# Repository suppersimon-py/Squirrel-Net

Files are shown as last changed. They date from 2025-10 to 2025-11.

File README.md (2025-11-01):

<div align="center">
  <a href="https://github.com/suppersimon-py">
    SupperSimon
  </a>

  <h2>Squirrel-Core</h2>
  <h2>NOT FINISHED</h2>
  <p>
    <strong>SquirrelCore</strong> is an open-source PCB built around the <strong>ESP32-S3</strong> and <strong>SX1262</strong>.
    It is designed for long-range mesh networking using the open-source 
    <a href="https://meshtastic.org" target="_blank" rel="noopener noreferrer">Meshtastic</a> firmware.
    It can function as a client, node, or repeater in a distributed network.
  </p>
</div>
<a href="https://github.com/suppersimon-py">
    
</a>
  <p>
    I wanted to design this as a challenge and a learning expirence on radio circuity for some time now, but without the funding (I'm kinda broke rn) this idea of mine wouldn't come to reality.
  </p>
  <h3>Continuing the development process</h3>
  <p>
    My plans are to not just stop on the PCB design but to also design a case around it. I am a visual modeler, I can't start work on the case until i have it in hand and can mesure and test fit,
    But I can assure I do have intresting design ideas for it. 
  </p>
  <p>
    Currently I have a github workflow that will automatically update, build, and release new versions of the meshtaic firmware to the realses page.
  </p>
  <p>
    I also need to fix somethings and test the actual firmware firmware.
  </p>

<div align="left">
  <h3>Features</h3>
  <ul>
    <li>ESP32-S3 microcontroller</li>
    <li>8MB Flash memory</li>
    <li>LoRaWAN, Wi-Fi, Bluetooth, and USB-C serial connectivity</li>
    <li>Adjustable battery charging: 400 mA or 1 A</li>
    <li>OLED display</li>
    <li>BME280 sensor (temperature, humidity, pressure)</li>
    <li>GPS module</li>
  </ul>
</div>

<div align="center">
  <h3>Meshtastic Links</h3>
  <p>
    <a href="https://meshtastic.org" style="text-decoration:none; font-weight:bold;">Get Started</a><br/>
    - <a href="https://meshtastic.org/docs/development/firmware/build">Building Instructions</a> – Learn how to compile the firmware from source.<br/>
    - <a href="https://meshtastic.org/docs/getting-started/flashing-firmware/esp32/">Flashing Instructions</a> – Install or update the firmware on your device.
  </p>
</div>

<div align="center">
  <h3>Licensing</h3>
</div>

<div align="left">
  <ul>
    <li>The core Meshtastic firmware in <code>/firmware/meshtastic</code> remains under its original license (as provided by the Meshtastic project).</li>
    <li>The SquirrelCore variant files in <code>/firmware/meshtastic/variants</code> are MIT-licensed (Copyright 2025 Supper Simon).</li>
    <li>When updating the repository, the variant is copied into Meshtastic, but the original Meshtastic license still applies to its code.</li>
  </ul>
</div>

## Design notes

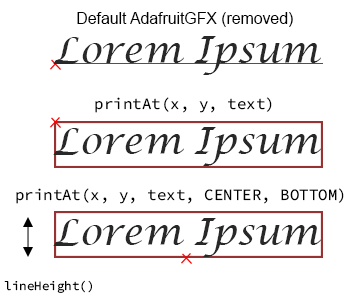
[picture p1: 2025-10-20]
firmware/meshtastic/src/graphics/niche/InkHUD/docs/appletfont.png

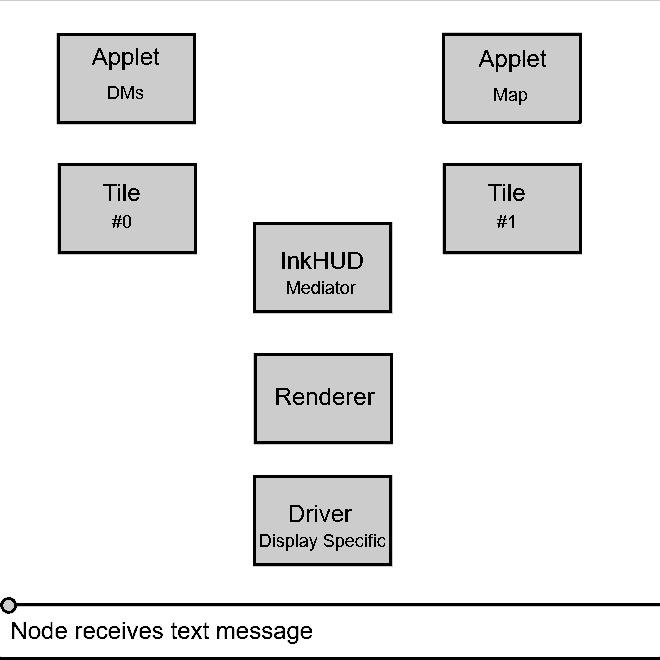
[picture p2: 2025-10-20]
firmware/meshtastic/src/graphics/niche/InkHUD/docs/rendering.gif

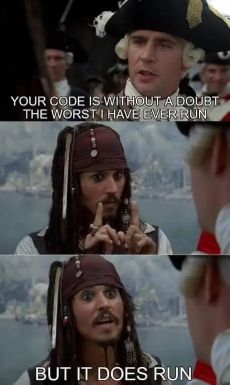
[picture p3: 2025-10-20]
firmware/meshtastic/src/graphics/niche/InkHUD/docs/disclaimer.jpg

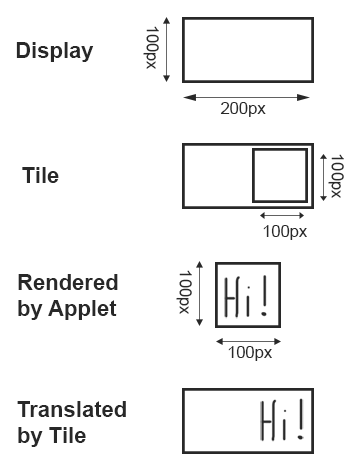
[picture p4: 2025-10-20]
firmware/meshtastic/src/graphics/niche/InkHUD/docs/tile_translation.png

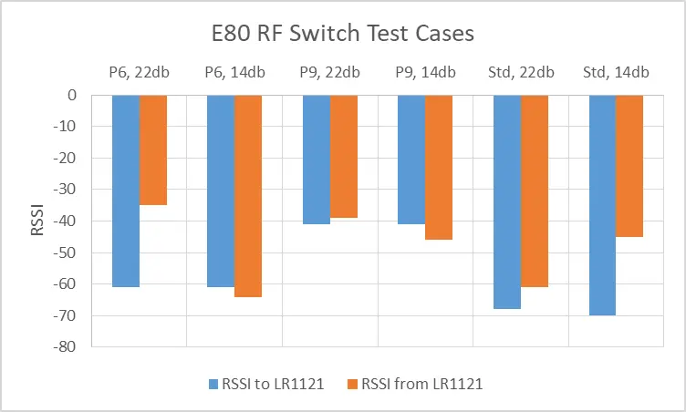
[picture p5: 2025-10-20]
firmware/meshtastic/variants/diy/nrf52_promicro_diy_tcxo/E80_RSSI_per_case.webp

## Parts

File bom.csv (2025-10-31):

id | designator | designation | qty per board | LCSC # | Footprint | PCBA Part | Price per Unit | Total Price | Purchased from
1 | Flash1 | Switch | 1 | 4809-SKRKAGE020CT-ND | SW_SPST_TS-1088-xR020 | no | 0.41 | 0.82 | digikey
2 | J5 | I2C OLED | 1 | 4863-WEA012832FWPP3N00000-ND | PinHeader_1x04_P2.54mm_Vertical | no | 5.02 | 10.04 | digikey
3 | BZ1 | Buzzer | 1 | 102-3761-1-ND | Buzzer_CUI_CPT-9019S-SMT | no | 1.82 | 3.64 | digikey
4 | J1 | Battery | 1 | 1471-MIKROE-4473-ND |  | no | 13.08 | 26.16 | digikey
5 | C1,C11,C12,C13,C16,C17,C19,C25,C28,C36,C38,C39 | 100nF | 12 | C307331,C1525,C49062 | 0402_1005 | yes | 0.0045 | 0.108 | JLC_PCBA
6 | C2,C8,C30 | 10uF | 3 | C15525 | 0402_1005 | yes | 0.0051 | 0.0306 | JLC_PCBA
7 | C3,C14,C49,C60 | 12pF | 4 | C1547 | 0402_1005 | yes | 0.0011 | 0.0088 | JLC_PCBA
8 | C4,C6,C24,C43,C44 | 1uF | 5 | C52923 | 0402_1005 | yes | 0.0029 | 0.029 | JLC_PCBA
9 | C5,C7,C10,C18,C20,C22,C23,C27 | 0.1uF | 8 | C1525 | 0402_1005 | yes | 0.0012 | 0.0192 | JLC_PCBA
10 | C9,C29,C42,C45 | 10 µF | 4 | C15525 | 0402_1005 | yes | 0.0051 | 0.0408 | JLC_PCBA
11 | C15,C50 | 47pF | 2 | C1567 | 0402_1005 | yes | 0.001 | 0.004 | JLC_PCBA
12 | C26 | 2.2u | 1 | C12530 | 0402_1005 | yes | 0.0024 | 0.0048 | JLC_PCBA
13 | C31 | 15pF | 1 | C1548 | 0402_1005 | yes | 0.001 | 0.002 | JLC_PCBA
14 | C32 | 1nF | 1 | C1523 | 0402_1005 | yes | 0.0011 | 0.0022 | JLC_PCBA
15 | C33 | 39pF | 1 | C1563 | 0402_1005 | yes | 0.0011 | 0.0022 | JLC_PCBA
16 | C34,C35 | 3.3pF | 2 | C1565 | 0402_1005 | yes | 0.001 | 0.004 | JLC_PCBA
17 | C37 | 470nF | 1 | C1623 | 0402_1005 | yes | 0.007 | 0.014 | JLC_PCBA
18 | C40 | 10nF | 1 | C15195 | 0402_1005 | yes | 0.007 | 0.014 | JLC_PCBA
19 | C41 | 0.1 µF | 1 | C1525 | 0402_1005 | yes | 0.0012 | 0.0024 | JLC_PCBA
20 | D1 | IR26-21C_L110_TR8 | 1 | C73929 | LED_SMD:LED_1206_3216Metric | yes | 0.0459 | 0.0918 | JLC_PCBA
21 | D3 | SS14 | 1 | C2480 | Diode_SMD:D_SMA | yes | 0.0149 | 0.0298 | JLC_PCBA
22 | D7 | LED_A_RGB | 1 | C6785001 | LED_SMD:LED_RGB_Wuerth_150080M153000 | yes | 0.7815 | 1.563 | JLC_PCBA
23 | J1 | XH-2AW | 1 | C157932 | JST_GH_SM02B-GHS-TB_1x02-1MP_P1.25mm_Horizontal | yes | 0.1328 | 0.2656 | JLC_PCBA
24 | J2 | USB_C_Receptacle_USB2.0_14P | 1 | C2894897 | USB_C_Receptacle_HCTL_HC-TYPE-C-16P | yes | 0.0888 | 0.1776 | JLC_PCBA
25 | J3 | Conn_Coaxial | 1 | C411563 | PCM_JLCPCB:IPEX-SMD_BWIPX-1-001E | yes | 0.0644 | 0.1288 | JLC_PCBA
26 | L3 | 2nH | 1 | C77103 | 0402_1005 | yes | 0.0057 | 0.0114 | JLC_PCBA
27 | L5 | 9.1nH | 1 | C74297 | 0402_1005 | yes | 0.0035 | 0.007 | JLC_PCBA
28 | L6 | 4.7nH | 1 | C13595 | 0402_1005 | yes | 0.0026 | 0.0052 | JLC_PCBA
29 | L8 | 15uH | 1 | C3221788 | 0402_1005 | yes | 1.1715 | 2.343 | JLC_PCBA
30 | Q1 | FS8205A | 1 | C908265 | SOP65P640X120-8N | yes | 0.0653 | 0.1306 | JLC_PCBA
31 | R1,R2 | 5K1 | 2 | C14677 | 0402_1005 | yes | 0.0011 | 0.0044 | JLC_PCBA
32 | R3 | 0R | 1 | C17168 | 0402_1005 | yes | 0.0005 | 0.001 | JLC_PCBA
33 | R4 | 1Ω | 1 | C25147 | 0402_1005 | yes | 0.0004 | 0.0008 | JLC_PCBA
34 | R5 | 1k | 1 | C11702 | 0402_1005 | yes | 0.0006 | 0.0012 | JLC_PCBA
35 | R6,R8,R17 | 3k | 3 | C25559 | 0402_1005 | yes | 0.0005 | 0.003 | JLC_PCBA
36 | R7 | 220k | 1 | C25546 | 0402_1005 | yes | 0.0004 | 0.0008 | JLC_PCBA
37 | R11,R14 | 4.7k | 2 | C25744 | 0402_1005 | yes | 0.0006 | 0.0024 | JLC_PCBA
38 | R12 | 1K | 1 | C861188 | 0402_1005 | yes | 0.0231 | 0.0462 | JLC_PCBA
39 | R13 | 100k | 1 | C25741 | 0402_1005 | yes | 0.0006 | 0.0012 | JLC_PCBA
40 | R15 | 1.2k | 1 | C25862 | 0402_1005 | yes | 0.0006 | 0.0012 | JLC_PCBA
41 | R21,R22 | 10K | 2 | C25744 | 0402_1005 | yes | 0.001 | 0.004 | JLC_PCBA
42 | U1 | BME280 | 1 | C92489 | Bosch_LGA-8_2.5x2.5mm_P0.65mm_ClockwisePinNumbering | yes | 2.9655 | 5.931 | JLC_PCBA
43 | U2 | PE4259 | 1 | C47117600 | bulk:SOT65P215X110-6N | yes | 0.1361 | 0.2722 | JLC_PCBA
44 | U3 | SX1262 | 1 | C191341 | Package_DFN_QFN:QFN-24-1EP_4x4mm_P0.5mm_EP2.6x2.6mm | yes | 3.102 | 6.204 | JLC_PCBA
45 | U4 | DW01A | 1 | C351410 | Package_TO_SOT_SMD:SOT-23-6 | yes | 0.0324 | 0.0648 | JLC_PCBA
46 | U6 | USBLC6-2SC6 | 1 | C7519 | Package_TO_SOT_SMD:SOT-23-6 | yes | 0.1013 | 0.2026 | JLC_PCBA
47 | U7 | ESP32-S3FN8 | 1 | C2913196 | QFN40P700X700X90-57N | yes | 3.942 | 7.884 | JLC_PCBA
48 | U8 | TP4056-42-ESOP8 | 1 | C16581 | SOIC-8-1EP_3.9x4.9mm_P1.27mm_EP2.41x3.3mm_ThermalVias | yes | 0.1719 | 0.3438 | JLC_PCBA
49 | U10 | AP2112K-3.3 | 1 | C23380830 | Package_TO_SOT_SMD:SOT-23-5 | yes | 0.0968 | 0.1936 | JLC_PCBA
50 | X1 | GPS_PA1010D | 1 | C9900050424 | Adafruit PA1010D Mini GPS:GPS_PA1010D | yes | 0.0365 | 0.073 | JLC_PCBA
51 | Y1 | 32.768 kHz | 1 | C32346 | Crystal:Crystal_SMD_3215-2Pin_3.2x1.5mm | yes | 0.1757 | 0.3514 | JLC_PCBA
52 | Y2 | Crystal_GND24 | 1 | C9900039190 | Crystal:Crystal_SMD_3225-4Pin_3.2x2.5mm | yes | 0.0365 | 0.073 | JLC_PCBA
53 | Y3 | 40MHz(10ppm) | 1 | C5261125 | Crystal:Crystal_SMD_2520-4Pin_2.5x2.0mm | yes | 0.0882 | 0.1764 | JLC_PCBA

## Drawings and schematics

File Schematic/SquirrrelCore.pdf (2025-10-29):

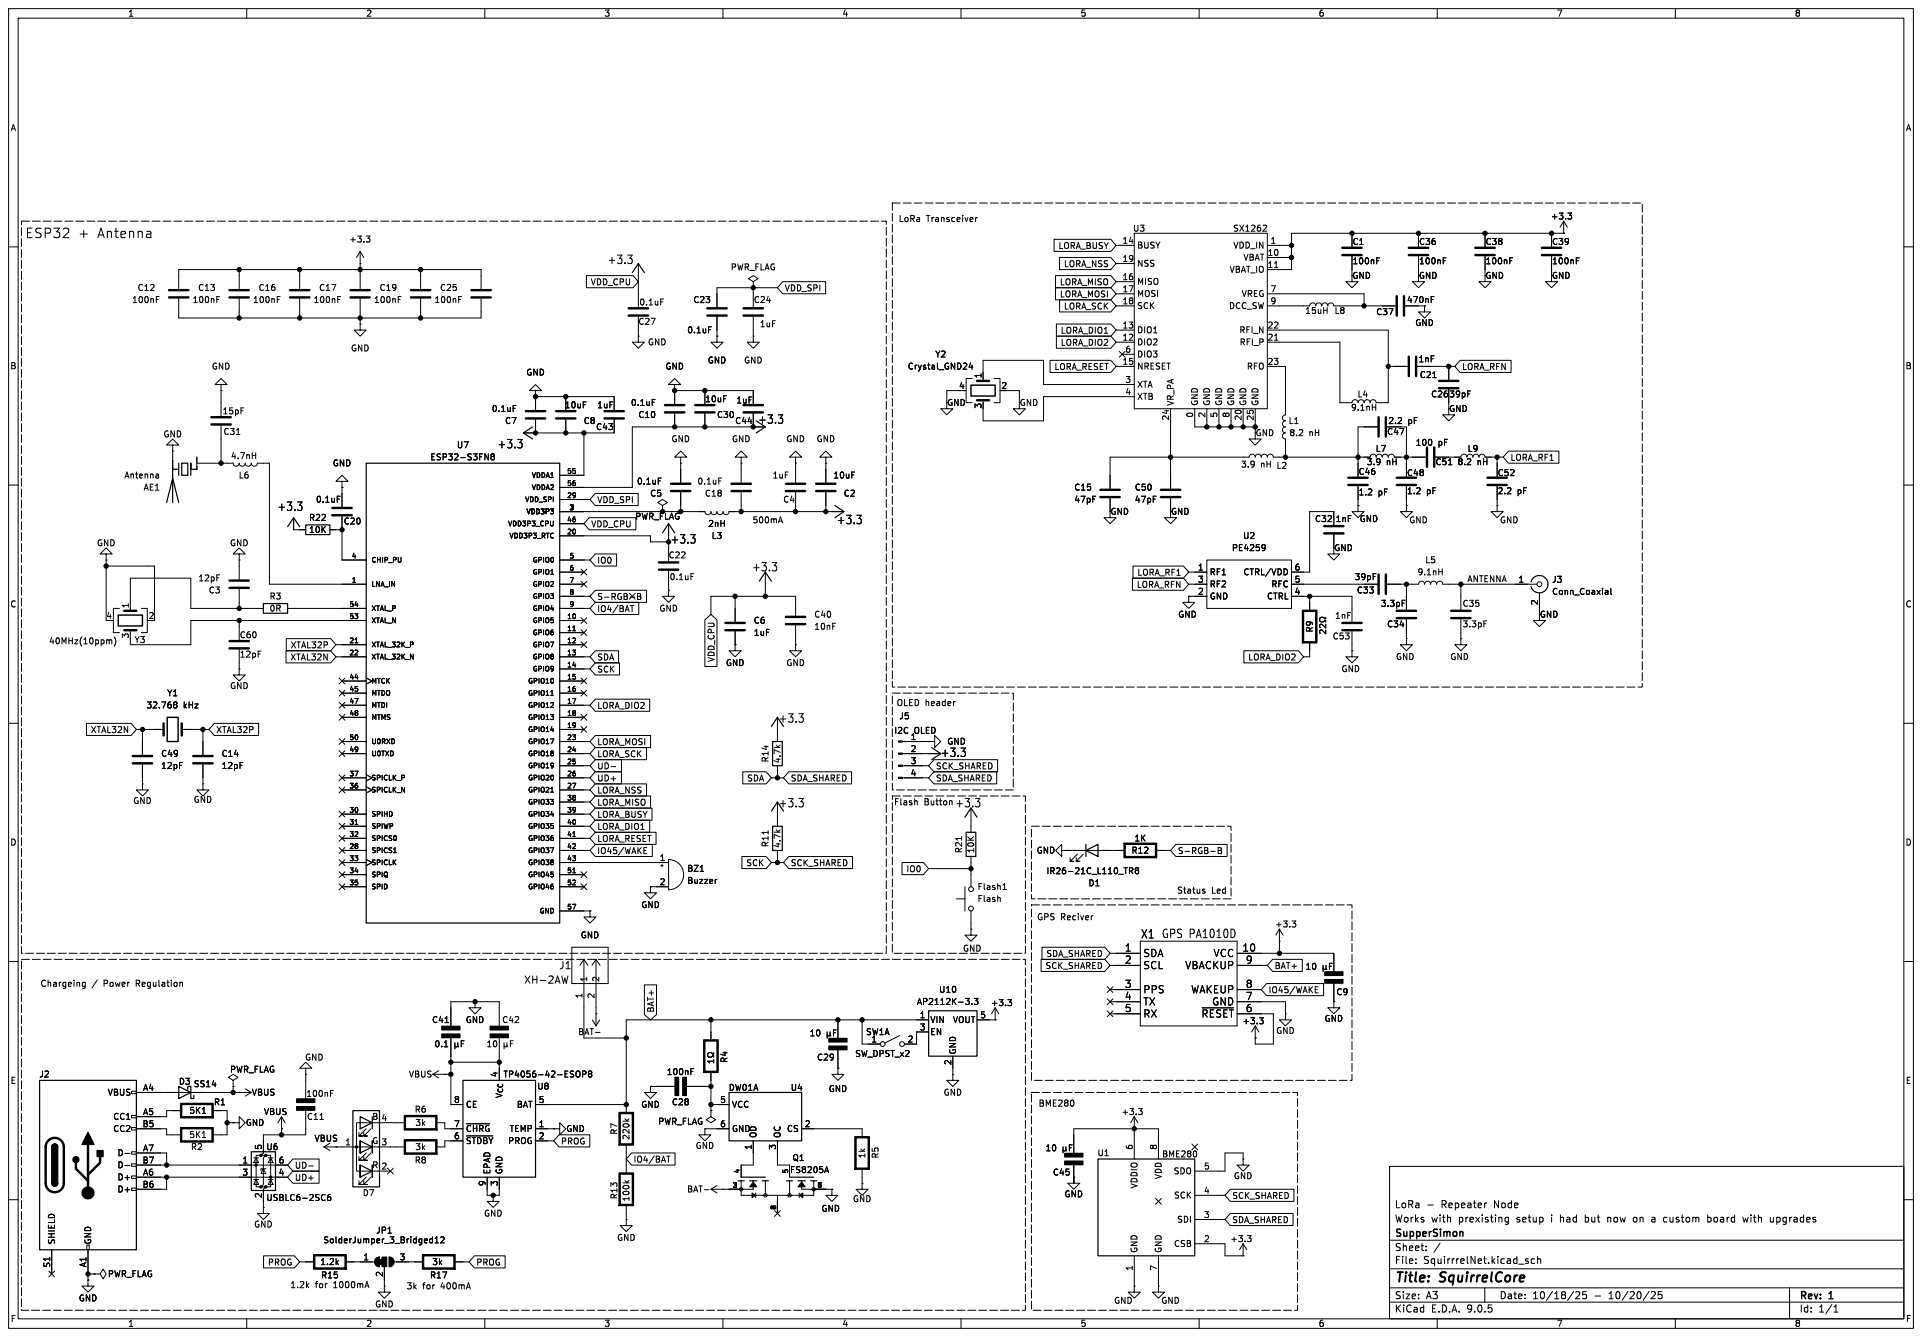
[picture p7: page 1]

8 GND 20 GND 25 VDD_IN 1 VBAT 10 VBAT_IO 11 VREG 7 DCC_SW 9 RFI_N 22 RFI_P 21 RFO 23 U3 SX1262 GND

1.2k for 1000mA Chargeing / Power Regulation

3 BAT 5 TEMP 1 PROG 2 GND

7 SDO 5 SCK 4 SDI 3 CSB 2 U1 BME280 GND

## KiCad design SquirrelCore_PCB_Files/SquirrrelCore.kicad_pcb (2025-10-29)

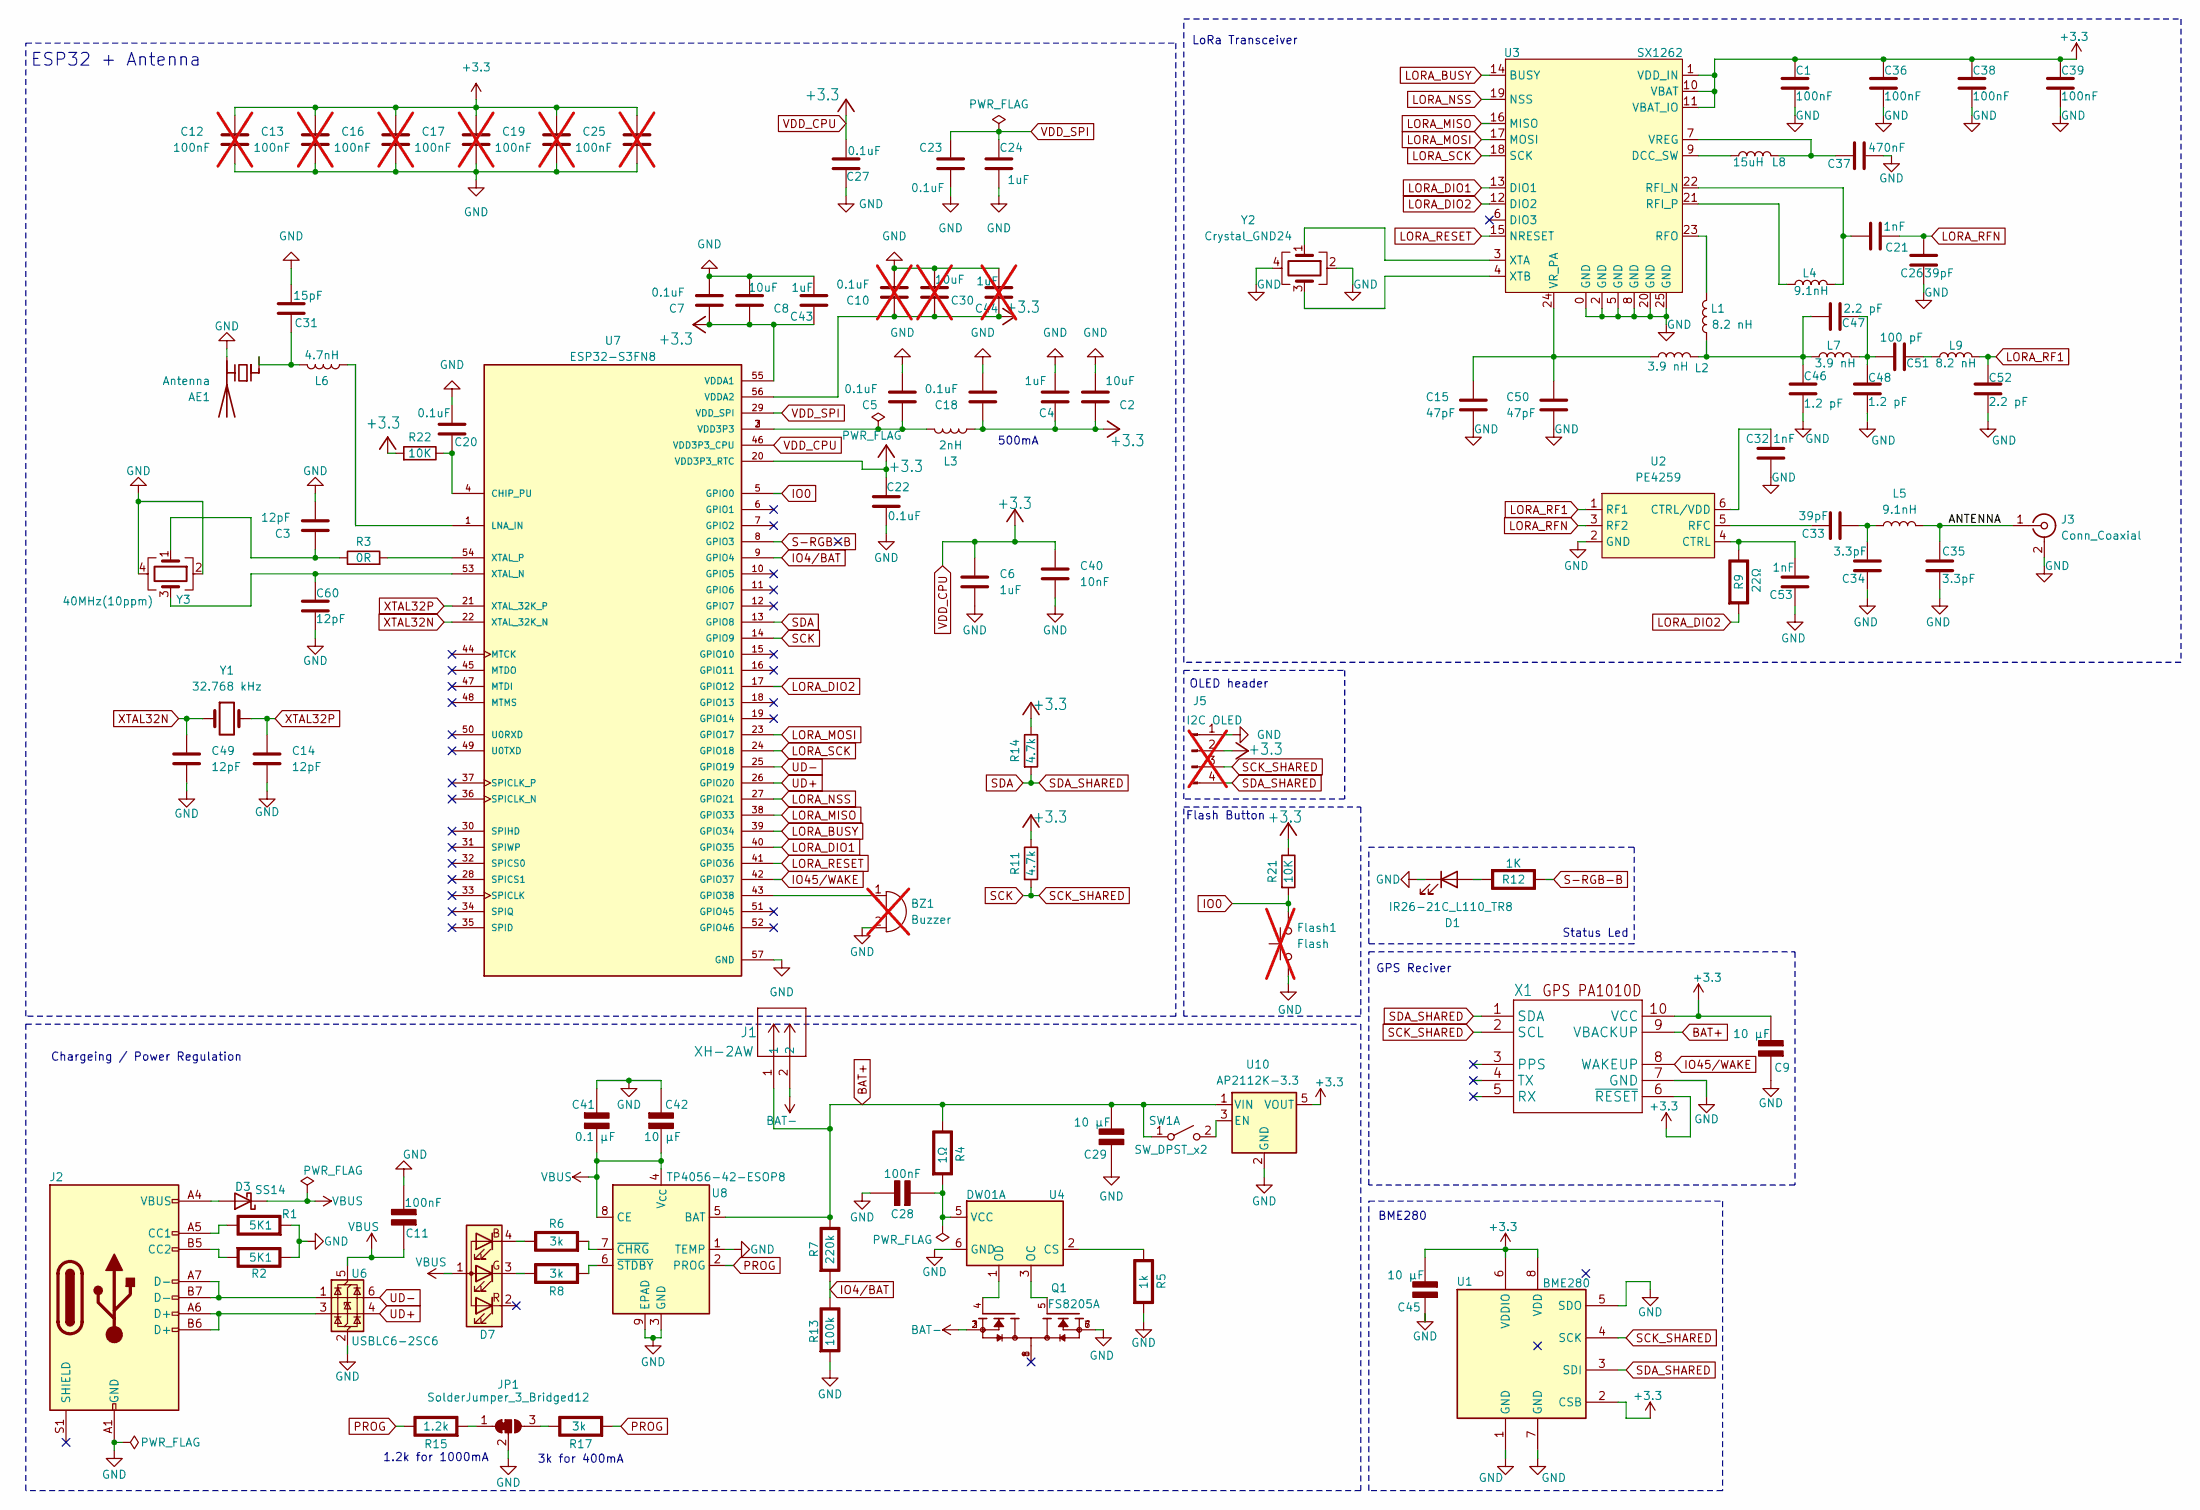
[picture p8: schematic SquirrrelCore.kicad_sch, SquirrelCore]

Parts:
AE1: Antenna; Texas_SWRA117D_2.4GHz_Left
BZ1: Buzzer; Buzzer_CUI_CPT-9019S-SMT; LCSC C95163; not fitted
C1, C36, C38, C39: 100nF; C_0402_1005Metric; LCSC C1525
C2, C8: 10uF; C_0402_1005Metric; MNF PART NUMBER C15525; LCSC C15525
C3, C14, C49, C60: 12pF; C_0402_1005Metric; MNF PART NUMBER C1547; LCSC C1547
C4, C6, C24, C43: 1uF; C_0402_1005Metric; MNF PART NUMBER C52923; LCSC C52923
C5, C7, C18, C20, C22, C23, C27: 0.1uF; C_0402_1005Metric; MNF PART NUMBER C1525; LCSC C1525
C9, C29, C42, C45: 10 µF; C_0402_1005Metric; Rating V; LCSC C15525
C10: 0.1uF; C_0402_1005Metric; MNF PART NUMBER C1525; LCSC C1525; not fitted
C11: 100nF; C_0402_1005Metric; Rating V; LCSC C307331
C12, C13, C16, C17, C19, C25: 100nF; C_0201_0603Metric; LCSC C49062; not fitted
C15, C50: 47pF; C_0402_1005Metric; LCSC C1567
C21: 1nF; C_0402_1005Metric; LCSC C1623
C26: 39pF; C_0402_1005Metric; LCSC C1623
C28: 100nF; C_0402_1005Metric; Rating V; LCSC C1525
C30: 10uF; C_0402_1005Metric; MNF PART NUMBER C15525; LCSC C15525; not fitted
C31: 15pF; C_0402_1005Metric; MNF PART NUMBER C1548; LCSC C1548
C32: 1nF; C_0402_1005Metric; LCSC C1523
C33: 39pF; C_0402_1005Metric; LCSC C1563
C34, C35: 3.3pF; C_0402_1005Metric; LCSC C1565
C37: 470nF; C_0402_1005Metric; LCSC C1623
C40: 10nF; C_0402_1005Metric; MNF PART NUMBER C15195; LCSC C15195
C41: 0.1 µF; C_0402_1005Metric; Rating V; LCSC C1525
C44: 1uF; C_0402_1005Metric; MNF PART NUMBER C52923; LCSC C52923; not fitted
C46, C48: 1.2 pF; C_0402_1005Metric; LCSC C1623
C47, C52: 2.2 pF; C_0402_1005Metric; LCSC C1623
C51: 100 pF; C_0402_1005Metric; LCSC C1623
C53: 1nF; C_0402_1005Metric; LCSC C1565
D1: IR26-21C_L110_TR8; LED_1206_3216Metric; LCSC C73929
D3: SS14; D_SMA; LCSC C2480
D7: LED_A_RGB; LED_RGB_Wuerth_150080M153000; LCSC C6785001
Flash1: Flash; SW_SPST_TS-1088-xR020; MNF PART NUMBER C318884; LCSC C318884; not fitted
J1: XH-2AW; CONN_XH-2AW_HRO; LCSC C157932
J2: USB_C_Receptacle_USB2.0_14P; USB_C_Receptacle_HCTL_HC-TYPE-C-16P-01A; LCSC C2894897
J3: Conn_Coaxial; IPEX-SMD_BWIPX-1-001E; LCSC C411563
J5: I2C OLED; PinHeader_1x04_P2.54mm_Vertical; LCSC C5248081; not fitted
JP1: SolderJumper_3_Bridged12; SolderJumper-3_P1.3mm_Bridged2Bar12_Pad1.0x1.5mm
L1, L9: 8.2 nH; L_0402_1005Metric; LCSC C3221788
L2, L7: 3.9 nH; L_0402_1005Metric; LCSC C3221788
L3: 2nH; L_0402_1005Metric; MNF PART NUMBER C77103; LCSC C77103
L4: 9.1nH; L_0402_1005Metric; LCSC C3221788
L5: 9.1nH; L_0402_1005Metric; LCSC C74297
L6: 4.7nH; L_0402_1005Metric; MNF PART NUMBER C13595; LCSC C13595
L8: 15uH; L_0402_1005Metric; LCSC C3221788
Q1: FS8205A; SOT-23-6; PARTREV 1.7; LCSC C908265
R1, R2: 5K1; C_0603; Rating W; LCSC C14677
R3: 0R; R_0402_1005Metric; MNF PART NUMBER C17168; LCSC C17168
R4: 1Ω; R_0402; Rating W; LCSC C25147
R5: 1k; R_0402; Rating W; LCSC C11702
R6, R8, R17: 3k; R_0402; Rating W; LCSC C25559
R7: 220k; R_0402; Rating W; LCSC C25546
R9: 22Ω; C_0402; Rating W; LCSC C861188
R11, R14: 4.7k; R_0402; MNF PART NUMBER C25744; LCSC C25744
R12: 1K; C_0603; Rating W; LCSC C861188
R13: 100k; R_0402; Rating W; LCSC C25741
R15: 1.2k; R_0402; Rating W; LCSC C25862
R21, R22: 10K; R_0402_1005Metric; MNF PART NUMBER C25744; LCSC C25744
SW1: SW_DPST_x2; SW_SPDT_CK_JS102011SAQN; LCSC C221660
U1: BME280; Bosch_LGA-8_2.5x2.5mm_P0.65mm_ClockwisePinNumbering; LCSC C92489
U2: PE4259; SOT65P215X110-6N; LCSC C47117600
U3: SX1262; QFN-24-1EP_4x4mm_P0.5mm_EP2.6x2.6mm; LCSC C191341
U4: DW01A; SOT-23-6; LCSC C351410
U6: USBLC6-2SC6; SOT-23-6; LCSC C7519
U7: ESP32-S3FN8; QFN40P700X700X90-57N; LCSC C2913196
U8: TP4056-42-ESOP8; SOIC-8-1EP_3.9x4.9mm_P1.27mm_EP2.41x3.3mm_ThermalVias; LCSC C16581
U10: AP2112K-3.3; SOT-23-5; LCSC C23380830
X1: GPS_PA1010D; LCSC C9900050424
Y1: 32.768 kHz; Crystal_SMD_3215-2Pin_3.2x1.5mm; MNF PART NUMBER C32346; LCSC C32346
Y2: Crystal_GND24; Crystal_SMD_3225-4Pin_3.2x2.5mm; LCSC C9900039190
Y3: 40MHz(10ppm); Crystal_SMD_2520-4Pin_2.5x2.0mm; MNF PART NUMBER C5261125; LCSC C5261125

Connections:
/ANTENNA: C35.1, J3.1 (In), L5.2
BAT+: C29.2 (-), J1.1, R4.1 (+), R7.1 (+), SW1.1 (A), U8.5 (BAT), U10.1 (VIN), X1.9 (VBACKUP)
BAT-: J1.2, Q1.2, Q1.3
GND: AE1.2 (PCB_Trace), BZ1.2 (-), C1.2, C2.2, C3.2, C4.2, C5.2, C6.2, C7.2, C8.2, C9.1 (+), C10.2, C11.2 (-), C12.2, C13.2, C14.2, C15.1, C16.2, C17.2, C18.2, C19.2, C20.2, C22.2, C23.2, C24.2, C25.2, C26.2, C27.2, C28.1 (+), C29.1 (+), C30.2, C31.2, C32.2, C34.1, C35.2, C36.2, C37.2, C38.2, C39.2, C40.2, C41.1 (+), C42.1 (+), C43.2, C44.2, C45.1 (+), C46.2, C48.2, C49.2, C50.1, C52.2, C53.1, C60.1, D1.1 (K), Flash1.1, J2.A1 (GND), J2.A12 (GND), J2.B1 (GND), J2.B12 (GND), J3.2 (Ext), J5.1, JP1.2 (C), Q1.6, Q1.7, R1.2 (-), R2.1 (+), R5.2 (-), R13.2 (-), U1.1 (GND), U1.5 (SDO), U1.7 (GND), U2.2 (GND), U3.0 (GND), U3.2 (GND), U3.5 (GND), U3.8 (GND), U3.20 (GND), U3.25 (GND), U4.6 (GND), U6.2 (GND), U7.57 (GND), U8.1 (TEMP), U8.3 (GND), U8.9 (EPAD), U10.2 (GND), X1.7 (GND), Y2.2, Y2.4, Y3.2, Y3.4
IO0: Flash1.2, R21.2, U7.5 (GPIO0)
IO4/BAT: R7.2 (-), R13.1 (+), U7.9 (GPIO4)
IO45/WAKE: U7.42 (GPIO37), X1.8 (WAKEUP)
LORA_BUSY: U3.14 (BUSY), U7.39 (GPIO34)
LORA_DIO1: U3.13 (DIO1), U7.40 (GPIO35)
LORA_DIO2: R9.2 (-), U3.12 (DIO2), U7.17 (GPIO12)
LORA_MISO: U3.16 (MISO), U7.38 (GPIO33)
LORA_MOSI: U3.17 (MOSI), U7.23 (GPIO17)
LORA_NSS: U3.19 (NSS), U7.27 (GPIO21)
LORA_RESET: U3.15 (NRESET), U7.41 (GPIO36)
LORA_RF1: C52.1, L9.2, U2.1 (RF1)
LORA_RFN: C21.2, C26.1, U2.3 (RF2)
LORA_SCK: U3.18 (SCK), U7.24 (GPIO18)
unnamed: AE1.1 (FEED), C31.1, L6.2
unnamed: BZ1.1 (+), U7.43 (GPIO38)
unnamed: C3.1, R3.1, Y3.1
unnamed: C5.1, L3.2, U7.2 (VDD3P3), U7.3 (VDD3P3)
unnamed: C28.2 (-), R4.2 (-), U4.5 (VCC)
unnamed: C33.2, C34.2, L5.1
unnamed: C46.1, C47.1, L1.1, L2.2, L7.1
unnamed: C47.2, C48.1, C51.1, L7.2
unnamed: C51.2, L9.1
unnamed: D1.2 (A), R12.2 (-)
unnamed: D3.2 (A), J2.A4 (VBUS), J2.A9 (VBUS), J2.B4 (VBUS), J2.B9 (VBUS)
unnamed: D7.4 (BA), R6.1 (+)
unnamed: D7.3 (GA), R8.1 (+)
unnamed: J2.A5 (CC1), R1.1 (+)
unnamed: J2.B5 (CC2), R2.2 (-)
unnamed: J2.A6 (D+), J2.B6 (D+), U6.3 (I/O2)
unnamed: J2.A7 (D-), J2.B7 (D-), U6.1 (I/O1)
unnamed: JP1.1 (A), R15.2 (-)
unnamed: JP1.3 (B), R17.1 (+)
unnamed: R5.1 (+), U4.2 (CS)
unnamed: R6.2 (-), U8.7 (~CHRG)
unnamed: R8.2 (-), U8.6 (~STDBY)
unnamed: C53.2, R9.1 (+), U2.4 (CTRL)
unnamed: SW1.2 (B), U10.3 (EN)
unnamed: C32.1, U2.6 (CTRL/VDD)
unnamed: C33.1, U2.5 (RFC)
unnamed: L8.1, U3.9 (DCC_SW)
unnamed: C21.1, L4.2, U3.22 (RFI_N)
unnamed: L4.1, U3.21 (RFI_P)
unnamed: L1.2, U3.23 (RFO)
unnamed: C37.1, L8.2, U3.7 (VREG)
unnamed: C15.2, C50.2, L2.1, U3.24 (VR_PA)
unnamed: U3.3 (XTA), Y2.1
unnamed: U3.4 (XTB), Y2.3
unnamed: Q1.5, U4.3 (OC)
unnamed: Q1.4, U4.1 (OD)
unnamed: C20.1, R22.1, U7.4 (CHIP_PU)
unnamed: L6.1, U7.1 (LNA_IN)
unnamed: C60.2, U7.53 (XTAL_N), Y3.3
unnamed: R3.2, U7.54 (XTAL_P)
PROG: R15.1 (+), R17.2 (-), U8.2 (PROG)
S-RGB-B: R12.1 (+), U7.8 (GPIO3)
SCK: J5.3, R11.2, U1.4 (SCK), U7.14 (GPIO9), X1.2 (SCL)
SDA: J5.4, R14.2, U1.3 (SDI), U7.13 (GPIO8), X1.1 (SDA)
UD+: U6.4 (I/O2), U7.26 (GPIO20)
UD-: U6.6 (I/O1), U7.25 (GPIO19)
VBUS: C11.1 (+), C41.2 (-), C42.2 (-), D3.1 (K), D7.1 (K), U6.5 (VBUS), U8.4 (V_{CC}), U8.8 (CE)
VDD_CPU: C1.1, C2.1, C4.1, C6.1, C7.1, C8.1, C9.2 (-), C10.1, C12.1, C13.1, C16.1, C17.1, C18.1, C19.1, C22.1, C25.1, C27.1, C30.1, C36.1, C38.1, C39.1, C40.1, C43.1, C44.1, C45.2 (-), J5.2, L3.1, R11.1, R14.1, R21.1, R22.2, U1.2 (CSB), U1.6 (VDDIO), U1.8 (VDD), U3.1 (VDD_IN), U3.10 (VBAT), U3.11 (VBAT_IO), U7.20 (VDD3P3_RTC), U7.46 (VDD3P3_CPU), U7.55 (VDDA1), U7.56 (VDDA2), U10.5 (VOUT), X1.6 (~RESET), X1.10 (VCC)
VDD_SPI: C23.1, C24.1, U7.29 (VDD_SPI)
XTAL32N: C49.1, U7.22 (XTAL_32K_N), Y1.1
XTAL32P: C14.1, U7.21 (XTAL_32K_P), Y1.2

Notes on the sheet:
Flash Button
Status Led
1.2k for 1000mA
3k for 400mA
ESP32 + Antenna
LoRa Transceiver
OLED header
GPS Reciver
Chargeing / Power Regulation
BME280
500mA

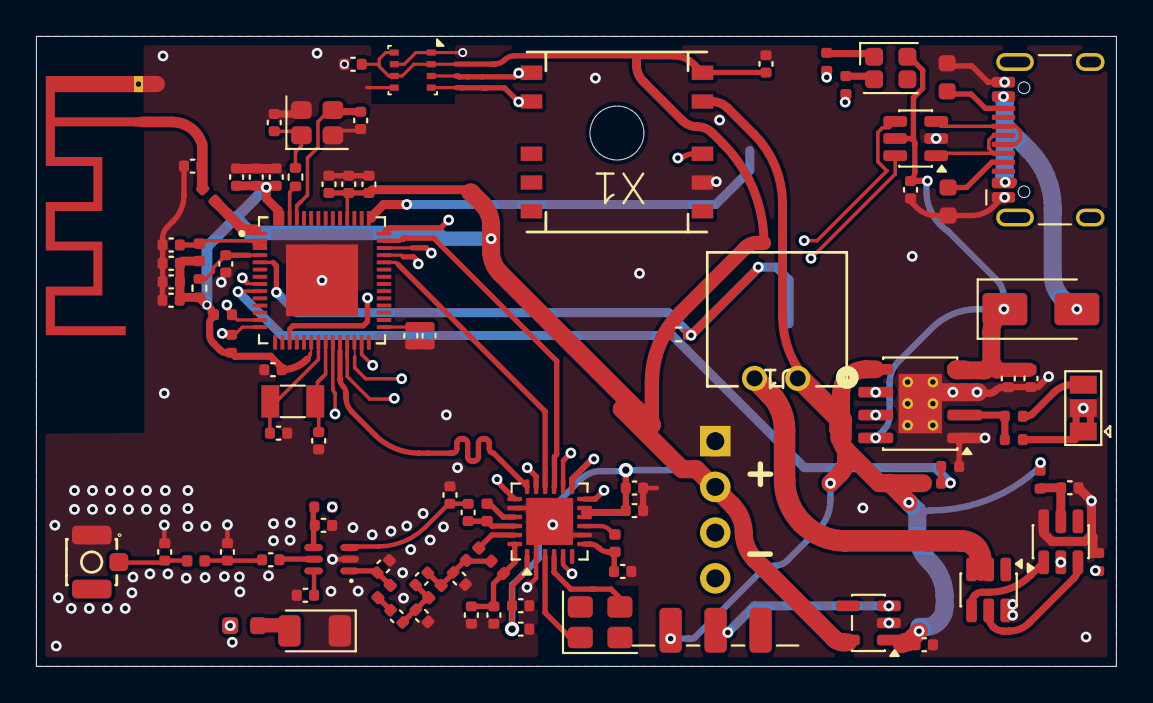
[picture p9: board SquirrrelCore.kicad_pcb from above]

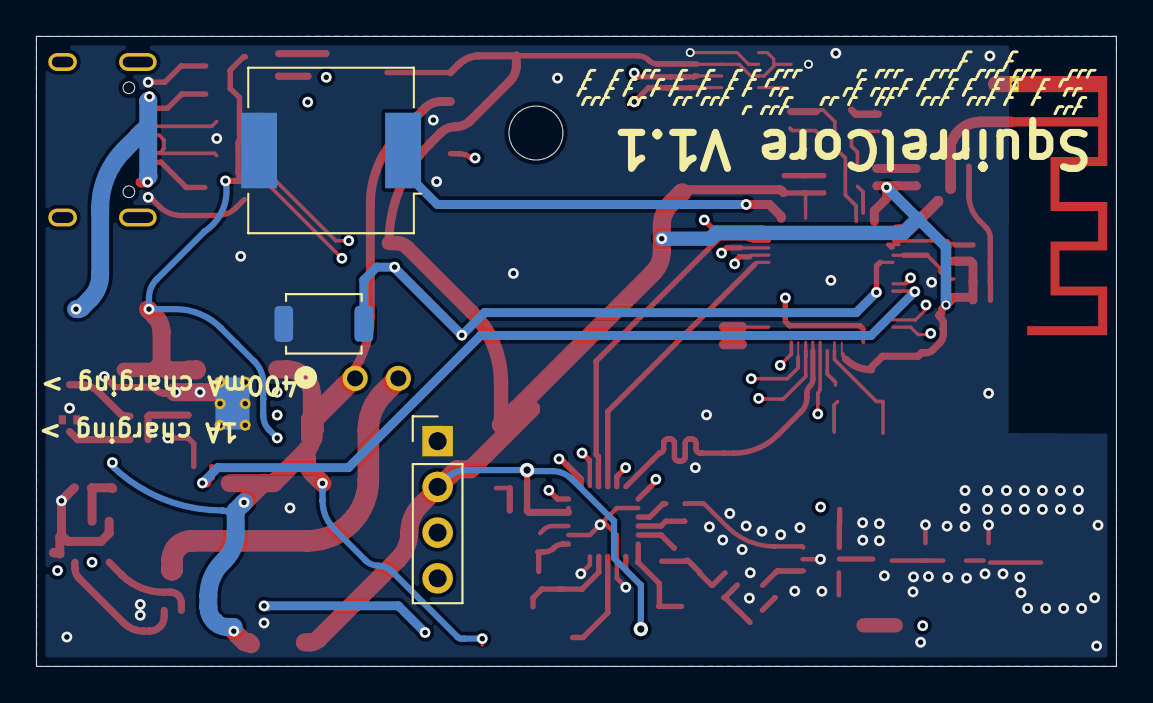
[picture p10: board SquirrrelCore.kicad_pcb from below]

Board: 4 copper layers, 60.0 x 35.0 mm, 97 parts (4 on the bottom side), 68 nets.

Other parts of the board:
svg2mod: G***; logo_F-SilkS

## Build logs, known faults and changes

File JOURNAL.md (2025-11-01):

<!--
  ===================    !!READ THIS NOTICE!!   ====================
  DO NOT edit this file manually. Your changes WILL BE OVERWRITTEN!
  This journal is auto generated and updated by Hack Club Blueprint.
  To edit this file, please edit your journal entries on Blueprint.
  ==================================================================
-->

## 10/19/2025 10 AM - Intro and Design Considerations  


I am fascinated by all forms of decentralized communication, such as Amateur radio and Packet Radio, so when I learned about **LoRaWAN (Long Range Wide Area Network)** operating in part of the 33cm ham band (In the US) but requiring **no license**, I was hooked.

I started off with a **Heltec V3** and 2 custom **Raspberry Pi Pico** setups as client nodes and got a pretty decent range of **2.7 miles** off its 100mW transmit power, but with more nodes, I can have a much more spread-out mesh to cover more area.

## Design Considerations

### 1. Using the ESP32
- **Extensive community support** It's one of the most well-documented and supported MCUs available.

### 2. Communication
- **LoRa** SX1262 seems to be my best option, it has libraries and good enough documentation.
- **Wi-Fi, Bluetooth** Keeping Wi-Fi and Bluetooth integration simple, I chose the ESP32-S3FN8 for its onboard 2.4G Wi-Fi and Bluetooth.

### 3. Power Management
- **3.3V for MCU and communication** to keep it simple, I chose a linear regulator, the AP2112K-3.3.
- **Battery Management** I've used the TP4056 in the past with good results, when set up correctly, only requiring a resistor change to change the charging current limit.

Edit 10/19/25:
Just realized I didn't really explain the name.

My dad set our first home Wi-Fi SSID as Fat Happy Squirrel for 2.4G way back in 2008. And ever since then, it's always been some variation of Squirrel this Squirrel that.  

## 10/19/2025 3 PM - Power Management Schematic  

### Implemented USBLC6-2SC6, TP4056, DW01A, and AP2122K-3.3
**USBLC6-2SC6**
- ESD protection for the **USB-C** charging/data port using the USBLC6-2SC6 to protect both data lines and VBUS.

**TP4056**
- Manages charging current limit, set by pulling PROG to GND.
- I am using a solder bridge to allow me to switch between 400mA and 1A  charge current without resoldering resistors.

**DW01A**
- Battery protection IC used as an overcharge and over-discharge shutoff.
- Required 2 MOSFETs to close/open BAT- to GND.

**AP2112K-3.3**
- Regulates Battery output to 3.3V
- Switched EN pin

USB-C protection:

Charge/Discharge Protection:

Current set, Solder Bridge:

Full Schematic:


## 10/19/2025 11 PM - MCU + Wi-Fi Schematic  

### Added MCU + Wi-FI to my Schematic
I did my own calculations for the Wi-Fi schematic using a handful of datasheets as a reference.

design notes:
- added I2C bus for planned future additions.
- Buzzer for notifications.
- Reset button skipped as my power regulator is switched, so to reset, I can power cycle.

Full Schematic:
  

## 10/20/2025 11 AM - SX1262 Schematic  

I followed the reference schematic for the **SX1262** provided in the data sheet. Although I do not need the RF switch, I left it in to make it easier to impedance match later, following more reference models.

Reference schematic:


I set all values to reflect 915MHz used in the US. I may go through the effort of making different versions for other locations, but for now, my schematic is only for North America, South America, and Australia.

Frequency map for LoRa:


My Schematic:
  

## 10/20/2025 3:27 PM - I2C devices added  

#### **GPS**
I will may replace this with an IC that allows for use of an external antenna.
**PA1010D Features:**
- I2C, Uart
- Embedded antenna
- Ultra High Sensitivity
- Positioning Accuracy < 3M
- Low Power Consumption, Acquisition 36mA, Tracking 28mA, Backup Mode 18uA

#### **OLED**
I chose something small 0.9" and cheap 2$, but should work just fine for my use.
**HS91L02W2C01 Features:**
- I2C
- 128x32
- Operating current 16mA

#### **Sensors**
Kept it simple with the BME280, it has plenty of library support for just about every use.

**BME280 Features:**
- LOW current draw, 3.6 µA @1Hz
- Humidity, Pressure, and Temperature 

###### **LED**
The led is used on start up and as a "heart beat" indicator while turned on.



## 10/20/2025 3:45 PM - Full Schematic  

### I've finished the schematic and will be moving on to PCB routing.
I'd be interested if anyone has any recommendations on making the schematic look better (It's my first). Feel free to start commenting on the Repo

**Schematic:**

[SquirrrelNet.kicad_sch](/user-attachments/blobs/proxy/eyJfcmFpbHMiOnsiZGF0YSI6Mzc5NiwicHVyIjoiYmxvYl9pZCJ9fQ==--8586e2a65835dfd7affac49baaaac2350a80c83e/SquirrrelNet.kicad_sch)  

## 10/20/2025 8 PM - Updated Projects GitHub  

I wrote an automation to update the meshtastic firmware in my repo, build updated firmware, and release the .bin and the source in a .zip, so when finished, my repo will always have updated builds/source for people to recreate my project.

**Learned** basic automation for GitHub Repos, I have ideas for future projects that will really help on.

Updated **Licensing** to separate my work from **Meshtastics**

I improved **README**, still needs work


Started writing the **Variant File** for SquirrelCore

Renamed the project to "SquirrelCore" to better reflect my development process, like a squirrel I just jump without thinking of the consequences or skills required, but someone comes out unscathed, usually with another skill in my toolbelt.  

## 10/21/2025 - Planing + Routed Power Management  

First, may I ask how y'all feel about rounded traces? I both love and hate them so much.

All my components were selected since they can be provided by JLCPCB. Unfortunately, I don't have the tools required for at-home assembly, so the majority of my parts are getting the old pick and place treatment, but I'm saving the larger ones for by hand.

I'm still finalizing the bill of materials. For the power switch, I'm reusing 100pc faceplate mount switches I got some time ago for really cheap. 

I plan on mounting the switch in a depression on the outside, allowing the legs to pass into the case onto the switch pads for soldering, then have a almost cover slide over the switch into rails on the case, locking the switch into place and preventing accidental use of the switch

I don't really have any size requirements for my PCB, so I picked a decent 60x35 mm 4-layer PCB
for now, it's tame, but I'm sure as soon as I start work on data lines, it's going to get interesting



  

## 10/22/2025 2 PM - Routed SX1262 + MCUs Wi-Fi antenna  

My placement for the **SX1262** is a bit close to the Wi-Fi antenna, but it's a small board, and I'm already a bit lacking in room; therefore, I'm not expecting great results for Wi-Fi. All I plan on using the antenna for is the on-board Bluetooth, so high bandwidth is not really a requirement for my design.

I am keeping most of my data traces at 0.3mm. My power max consumption should only ever peak around 300mA, so my choice of 1mm (external layers only) power traces should be more than sufficient.



The board is already starting to feel small. The remaining components will surely be fun to add and route.

I've been doing my routing without the Fab layer on..... Looks great, but I'll fix that next.


I exported my board as a .GLB and imported it into **Blender** for rendering. I'm also trying to relearn it since it's been a hot minute since I've used it for modeling, and I want to try and use it to build the case. 

I will not include the time spent working in Blender for renders of my board in the build time, since when I change values too fast with my preferred 2-cycled rendered port views, it just crashes.


For my layout of the **SX1262**, I used a reference (provided below) as just a starting place for my design; it really didn't help that much.
Mine:


Semtech SX1276 **reference**:

[SX1272MB2DAS_e364v02a_layout_top.pdf](/user-attachments/blobs/proxy/eyJfcmFpbHMiOnsiZGF0YSI6NDQ5NywicHVyIjoiYmxvYl9pZCJ9fQ==--8db85e5b66c8c142cd38290b68022213d6478b6f/SX1272MB2DAS_e364v02a_layout_top.pdf)
[SX1272MB2DAS_e364v02a_layout_bottom.pdf](/user-attachments/blobs/proxy/eyJfcmFpbHMiOnsiZGF0YSI6NDQ5NiwicHVyIjoiYmxvYl9pZCJ9fQ==--df67da55dbdda5cc3dd9542fa1cc213ba58f0f72/SX1272MB2DAS_e364v02a_layout_bottom.pdf)  

## 10/22/2025 9 PM - Built a small scene for project renders  

A simple box to make images and animations in


I just made textured planes for the walls, a simple wooden plane as a floor, and a glass display base. I have a good GPU, so all my renders will be using Cycles rendering in 4K with 8000 samples, which looks great for all except the board. In my final iteration, I'll change the material properties for the board even further, hopefully getting a good result.

It renders decent images, but I believe it will look much better rendering videos of it rotating
 
Result:


I figured out why Blender was crashing so much:

37K faces

## 10/28/2025 1 PM - Almost finished the board design  

I've connected all components and am now just going through everything again to clean things up and check connections.

I've also decided to skip some components from the schematic since some power pins are so close to each other.



I've made my BOM; however, I'm still trying to optimize it. The lowest amount of PCBs I can manufacture is 5, and I don't have the at-home capacity to assemble them, so it's gonna be more than anticipated for components and assembly.

I find it crazy that the PCB itself is so cheap compared to buying all the components:


BOM


[bom](/user-attachments/blobs/proxy/eyJfcmFpbHMiOnsiZGF0YSI6NjI0MywicHVyIjoiYmxvYl9pZCJ9fQ==--0b7bab9bc02c4dda49767a8385d1ab951437e62e/bom.csv)  

## 10/28/2025 7 PM - Finding replacement parts for Out of stock components  

I'm my design, I used the Johanson-0900FM15D0039E in my SX1262 RF track, however, it's out of stock so I need to find a replacement


Same with the pa1010d (GPS) being unavailable.

My current plan is to pass on the GPS (For Now) and just focus on my RF path.

I've also finished all my PCB routing and fixed all the connection errors. There were many.
SquirrrelNet

## 10/29/2025 11 AM - redesigning the SX1262 Transceiver  

The saw filter (0900FM15D0039E) I was using in my schematic is out of stock, so I'm skipping it.

I'm currently working on using the SX1262 evaluation board as a reference; however, I will still need to come up with the component values.

And to top that all off, I'm sick while doing this :(




## 10/29/2025 2 PM - Updated SX1262  

This doesn't look nearly as clean, and I think I messed up the impedance matching, but I built a basic filter following the reference schematic and some values from other boards







## 10/29/2025 9 PM - PCB finished  

PCB routing done, and PCBs BOM done.



Updated the SX1262 for a more visually interesting appearance and a little more space optimization.

I'm now updating GitHub with the project files and finishing the hand-soldered components selection.



I skipped the BME280 for now since it costs so much for both the raw parts, and with it I would need to upgrade the standard assembly instead of the economical, so it's a win-win budget cut.
The current PCB/PCBA cost:   

## 10/31/2025 - Almost Finished  

I have finished the bill of materials and got the final quotes for a minimum of 2 PCBA. To optimize cost, I omitted the BME280 in the PCBA.

I know it's more expensive, but I don't like the idea of cheaping out on batteries, so the few small components I'm not getting in the PCBA I'm getting off DigiKey instead of someplace cheaper.

While doing all this, I realized I had flipped the display pin header, so I fixed that. I'm really glad I caught that.

I'm taking a break from this for the next few days. I have a concerning wet cough, and it's hard to think straight. See ya'll sometime next week.

Estimated 187.34$ for 2 (cost optimized) boards



[bom](/user-attachments/blobs/proxy/eyJfcmFpbHMiOnsiZGF0YSI6NjkxMCwicHVyIjoiYmxvYl9pZCJ9fQ==--7b749d395276e4396c85c1e358290123d889f8ab/bom.csv)

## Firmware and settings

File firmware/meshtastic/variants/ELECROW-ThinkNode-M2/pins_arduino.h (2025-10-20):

// Need this file for ESP32-S3
// No need to modify this file, changes to pins imported from variant.h
// Most is similar to https://github.com/espressif/arduino-esp32/blob/master/variants/esp32s3/pins_arduino.h

#ifndef Pins_Arduino_h
#define Pins_Arduino_h

#include <stdint.h>
#include <variant.h>

#define USB_VID 0x303a
#define USB_PID 0x1001

// Serial
static const uint8_t TX = UART_TX;
static const uint8_t RX = UART_RX;

// Default SPI will be mapped to Radio
static const uint8_t SS = LORA_CS;
static const uint8_t SCK = LORA_SCK;
static const uint8_t MOSI = LORA_MOSI;
static const uint8_t MISO = LORA_MISO;

// The default Wire will be mapped to PMU and RTC
static const uint8_t SCL = I2C_SCL;
static const uint8_t SDA = I2C_SDA;

#endif /* Pins_Arduino_h */

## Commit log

2025-10-20 Auto-update Meshtastic to v2.6.11.60ec05e
    [.isort.cfg, configuration.h, partition-table.csv]
2025-10-24 Added the bill of materials
    [bom.csv]
